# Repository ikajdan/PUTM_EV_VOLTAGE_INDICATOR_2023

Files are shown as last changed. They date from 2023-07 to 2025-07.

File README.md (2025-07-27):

# Voltage Indicator

This repository contains the hardware design files for a voltage indicator used in the accumulator of a Formula Student electric vehicle. The voltage indicator is a safety feature that provides a visual indication when the voltage exceeds a safe threshold. The voltage indicator is designed to meet the requirements of the Formula Student EV rulebook and ensure the safety of the accumulator during operation.

The rules state that the connection status must be clearly visible, and electrically controlled switches are not allowed. A visible indicator, such as a voltmeter or red LED, must illuminate when voltage exceeds 60 V DC or half the maximum TS voltage. This indicator must be clearly marked as a "Voltage Indicator", visible during disconnection, and function independently of software control, always powered by the TS, even when the accumulator is removed.

<br>
<div align="center">
  
  <br><br>
  <em>PCB layout of the voltage indicator.</em>
</div>
<br>

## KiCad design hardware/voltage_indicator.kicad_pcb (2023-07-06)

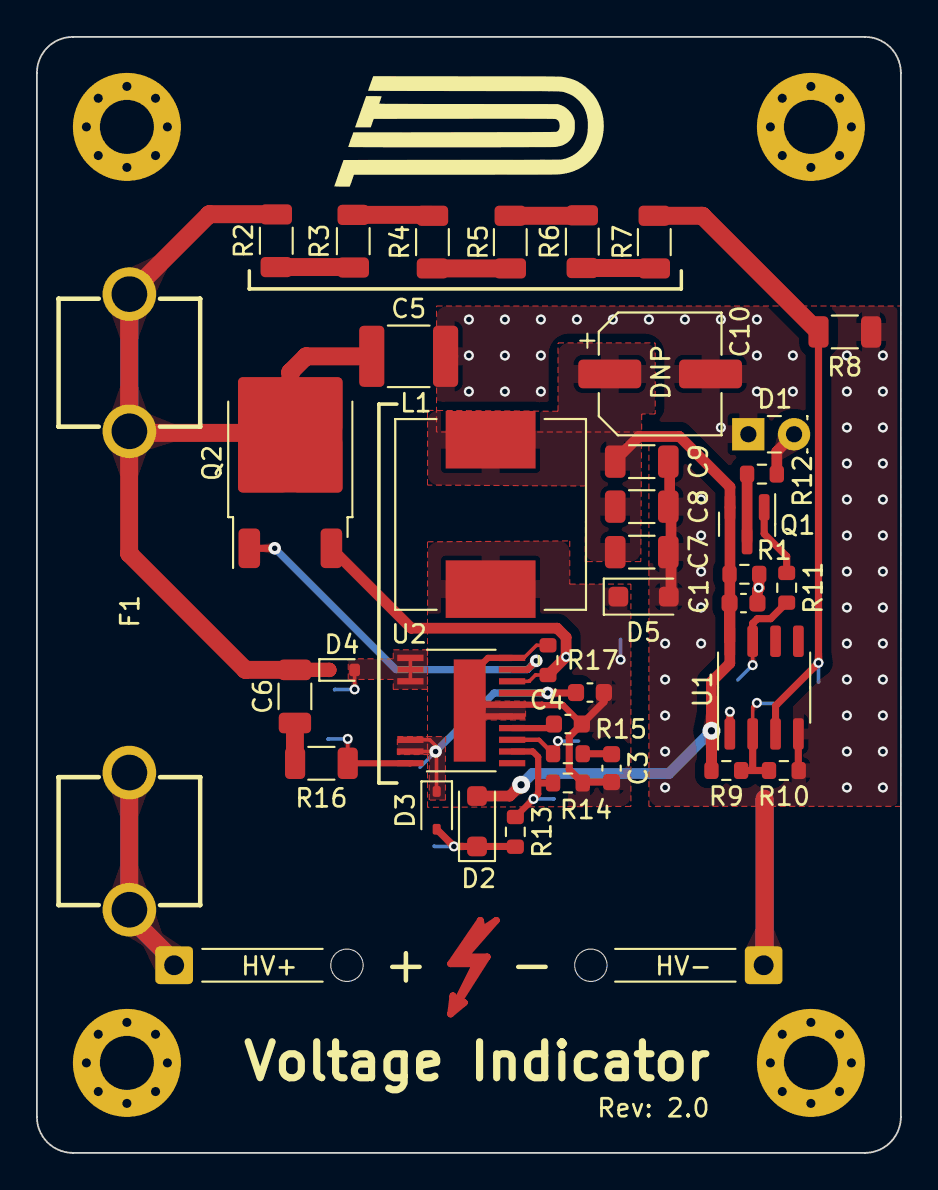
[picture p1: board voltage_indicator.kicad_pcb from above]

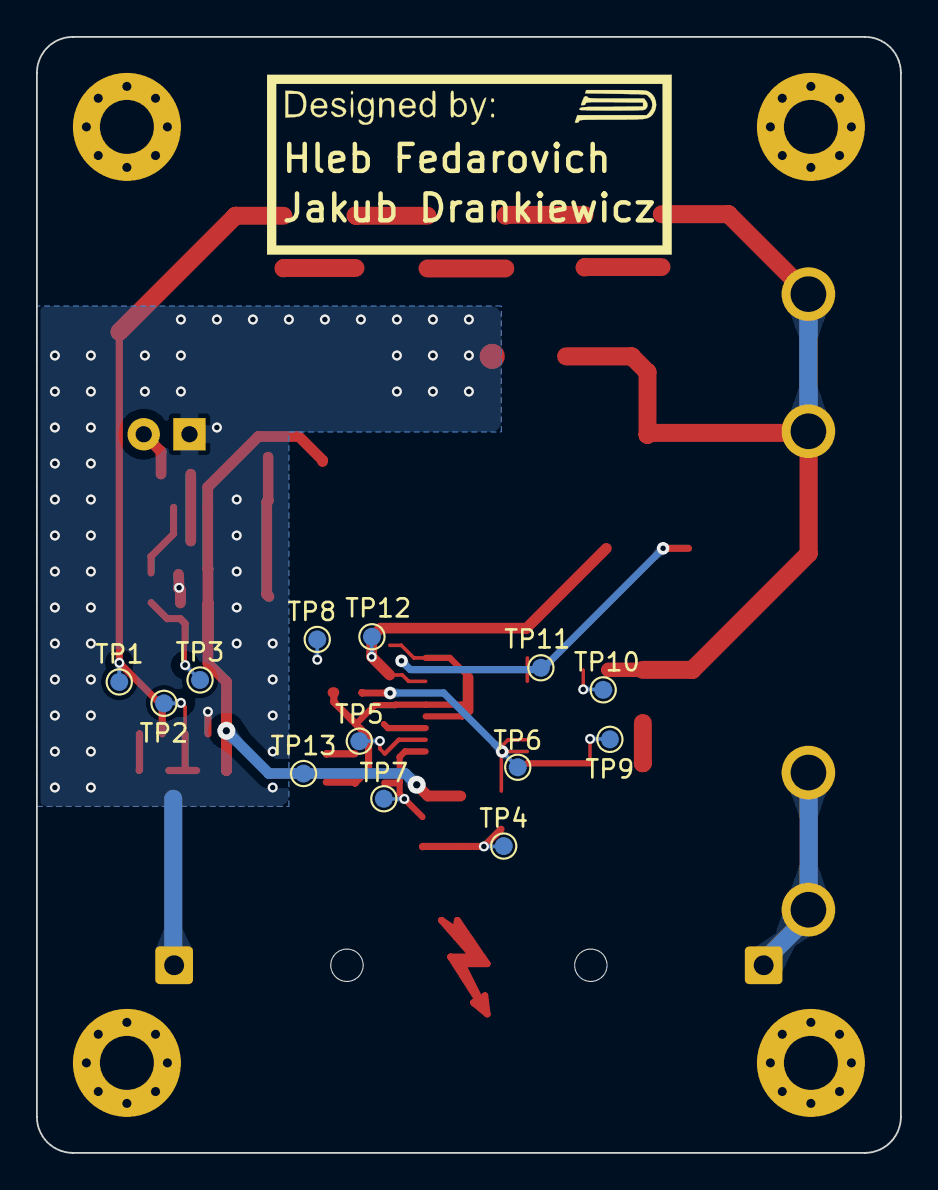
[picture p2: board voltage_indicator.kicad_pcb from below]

Board: 2 copper layers, 48.0 x 62.0 mm, 53 parts (13 on the bottom side), 27 nets.

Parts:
C1, C3, C4: 100n; C_0603_1608Metric
C2: 10u; C_0603_1608Metric
C5: 100n; C_1812_4532Metric
C6: 10p; C_1206_3216Metric
C7, C8, C9: 47u; C_1206_3216Metric
C10: 330u; CP_Elec_6.3x5.4
D1: Red; LED_Rectangular_W3.9mm_H1.9mm
D2, D5: US1KFA; D_SOD-123F
D3: CMDSH2-3; D_SOD-323
D4: 10V; D_SOD-523
F1: 600V; FuseClip
J1: HV+; SolderWire_Relief
J2: HV-; SolderWire_Relief
L1: 1m; WurthElektronikInductor_7687714102
Q1: BC807; SOT-23
Q2: TK3P80ERQ; TO-252-2
R1: 1k; R_0603_1608Metric
R2, R3, R4, R5, R6, R7: 100k; R_1206_3216Metric
R8, R16: 10k; R_1206_3216Metric
R9: 3k; R_0603_1608Metric
R10: 240R; R_0603_1608Metric
R11: 1k5; R_0603_1608Metric
R12: 470R; R_0603_1608Metric
R13: 21k5; R_0603_1608Metric
R14: 2k49; R_0603_1608Metric
R15: 22k1; R_0603_1608Metric
R17: 220m; R_0603_1608Metric
TP1: LM_N; TestPoint_Pad_D1.0mm
TP2: LM_P; TestPoint_Pad_D1.0mm
TP3: LM_OUT; TestPoint_Pad_D1.0mm
TP4: LT_D3; TestPoint_Pad_D1.0mm
TP5: LT_VC; TestPoint_Pad_D1.0mm
TP6: LT_BIAS; TestPoint_Pad_D1.0mm
TP7: LT_FB; TestPoint_Pad_D1.0mm
TP8: LT_GND; TestPoint_Pad_D1.0mm
TP9: LT_DCM; TestPoint_Pad_D1.0mm
TP10: LT_VIN; TestPoint_Pad_D1.0mm
TP11: LT_GATE; TestPoint_Pad_D1.0mm
TP12: LT_SENSE; TestPoint_Pad_D1.0mm
TP13: LT_VOUT; TestPoint_Pad_D1.0mm
U1: LM211DT; SO-8_3.9x4.9mm_P1.27mm
U2: LT8316EFE

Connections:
+12V: C1.1, C7.2, C8.2, C9.2, C10.1, D2.2 (A), L1.2, Q1.2 (E), R1.1, R9.2, TP13.1, U1.8 (V+)
GND: C1.2, C5.2, C7.1, C8.1, C9.1, C10.2, D1.1 (K), D5.2 (A), J2.1, R1.2, R8.1, R10.1, U1.1 (GND), U1.4 (V-)
unnamed: C3.1, R15.1
unnamed: C6.1, R16.1
unnamed: D1.2 (A), R12.2
unnamed: D2.1 (K), D3.2 (A), R13.2, TP4.1
unnamed: C2.1, D3.1 (K), TP6.1, U2.8 (INTVCC), U2.9 (BIAS), U2.17 (EN/UVLO)
unnamed: D4.2 (A), TP10.1, U2.1 (VIN), U2.2 (VIN), U2.3 (VIN)
unnamed: C2.2, C3.2, C4.2, D5.1 (K), L1.1, R14.1, R17.1, TP8.1, U2.15 (GND), U2.16 (SMODE), U2.20 (GND), U2.EPAD
unnamed: F1.2, J1.1
unnamed: Q1.1 (B), R11.2
unnamed: Q1.3 (C), R12.1
unnamed: Q2.1 (G), TP11.1, U2.19 (GATE)
unnamed: Q2.3 (S), R17.2, TP12.1, U2.18 (SENSE)
unnamed: R2.1, R3.2
unnamed: R3.1, R4.2
unnamed: R4.1, R5.2
unnamed: R5.1, R6.2
unnamed: R6.1, R7.2
unnamed: R11.1, TP3.1, U1.7
unnamed: R9.1, R10.2, TP2.1, U1.2 (+)
unnamed: R7.1, R8.2, TP1.1, U1.3 (-)
unnamed: R16.2, TP9.1, U2.10 (DCM)
unnamed: R13.1, R14.2, TP7.1, U2.12 (FB)
unnamed: C4.1, U2.14 (IREG/SS)
unnamed: R15.2, TP5.1, U2.13 (VC)
VCC: C5.1, C6.2, D4.1 (K), F1.1, Q2.2 (D), R2.2

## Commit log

2022-11-29 change scheme of LT8316EFE and change mosfet symbol
    [PUTM_VOLTAGE_INDICATOR_2023.kicad_sch, lt8316.kicad_sch]
2022-12-06 add all the needed components
    [PUTM_VOLTAGE_INDICATOR_2023.kicad_sch]
2022-12-06 gitignore change + capacitors improve
    [PUTM_VOLTAGE_INDICATOR_2023.kicad_sch, lt8316.kicad_sch]
2022-12-06 dodaję fus, wybieram led, zmieniam komparator, dodaję datasheety
    [PUTM_VOLTAGE_INDICATOR_2023.kicad_sch, lt8316.kicad_sch]
2022-12-09 add resistors / add footprints and datasheets/ change symbols
    [PUTM_VOLTAGE_INDICATOR_2023.kicad_sch, lt8316.kicad_sch]
2022-12-10 add pcb
    [PUTM_VOLTAGE_INDICATOR_2023.kicad_pcb, PUTM_VOLTAGE_INDICATOR_2023.kicad_sch, lt8316.kicad_sch]
2022-12-11 resistors change; elements placed; new footprints
    [01020071Z-FUSE-CLIP.PcbLib, 01020071Z.SchLib, 01020071Z.stp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]
2022-12-11 pcb edit
    [PUTM_VOLTAGE_INDICATOR_2023.kicad_pcb, PUTM_VOLTAGE_INDICATOR_2023.kicad_sch, lt8316.kicad_sch]
2022-12-11 pcb update
    Changed converter layout, fuse footprint
    [PUTM_VOLTAGE_INDICATOR_2023.kicad_pcb]
2022-12-11 Update PUTM_VOLTAGE_INDICATOR_2023.kicad_pcb
    pcb update
    [PUTM_VOLTAGE_INDICATOR_2023.kicad_pcb]
2022-12-11 cleanup
    cleaned up some traces, fixed DRC errors
    [PUTM_VOLTAGE_INDICATOR_2023.kicad_pcb]
2022-12-13 symbol changed / resistor values changed
    [PUTM_VOLTAGE_INDICATOR_2023.kicad_pcb, PUTM_VOLTAGE_INDICATOR_2023.kicad_sch, lt8316.kicad_sch]
2022-12-14 fuse position changed/ small pcb updates
2022-12-15 pcb update / resistor values
    [PUTM_VOLTAGE_INDICATOR_2023.kicad_pcb, PUTM_VOLTAGE_INDICATOR_2023.kicad_sch]
2023-03-26 Cleanup the project
    [01020071Z-FUSE-CLIP.PcbLib, 01020071Z.SchLib, 01020071Z.stp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]
2023-05-06 Improve the layout
    [power.kicad_sch, voltage_indicator.kicad_pcb, voltage_indicator.kicad_sch]
2023-05-06 Remove teardrops from SMD pads
    [voltage_indicator.kicad_pcb]
2023-05-07 Use a transistor to drive the LED
    [power.kicad_sch, voltage_indicator.kicad_pcb, voltage_indicator.kicad_sch]
2023-05-07 Align the signature box
    [voltage_indicator.kicad_pcb]
2023-07-06 Update component values
    [power.kicad_sch, voltage_indicator.kicad_pcb, voltage_indicator.kicad_sch]

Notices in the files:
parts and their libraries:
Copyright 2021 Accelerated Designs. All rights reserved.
